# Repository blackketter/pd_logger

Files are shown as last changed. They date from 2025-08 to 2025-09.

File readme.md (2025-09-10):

# USB-C Power Delivery Measurement Tools

This repository contains two DIY gadgets to monitor and log **USB-C Power Delivery (PD)**.  
Both devices are designed to be easy to build, hackable, and useful for makers who want to explore USB-C PD.

---

## ✨ Features

- **DIY Power Meter**  
  Small device with an OLED display showing **voltage, current, and power** in real time.  
  Powered by an STM32 microcontroller.

- **PD Logger**  
  Wi-Fi enabled device based on ESP-01s.  
  Logs **voltage, current, and power** for several hours and serves interactive plots in any web browser.

---

## 📷 Devices

### Power Meter
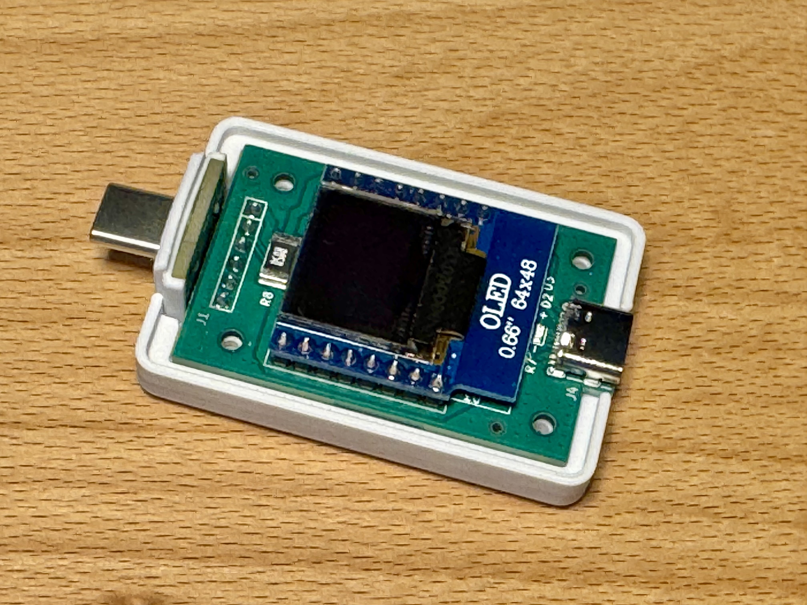
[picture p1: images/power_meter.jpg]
DIY Power Meter


### PD Logger
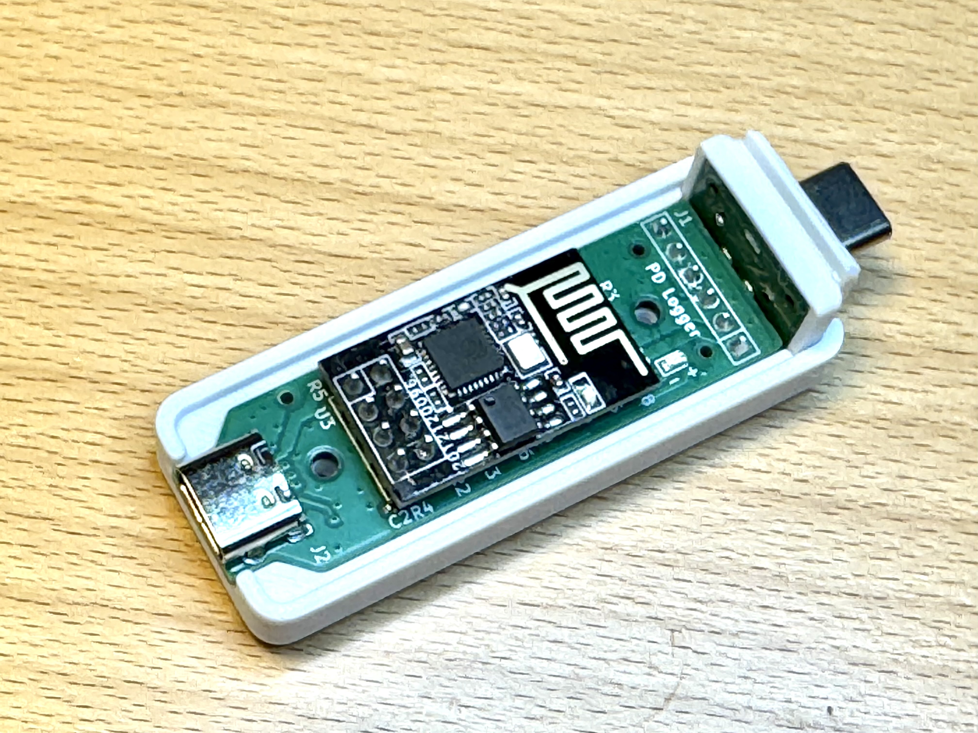
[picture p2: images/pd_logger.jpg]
PD Logger


---

## 🛠️ How it works

- **USB-C connectors**: male on the input side, female on the output side.  
- **CC & VCONN lines** are passed through to handle PD voltage negotiation.  
- **Shunt resistor (50 mΩ)** allows precise current measurement.  
- **INA219 sensor** measures voltage and current via I²C.  
- **Step-down converter** generates 3.3 V from 5–20 V input.  
- **MCUs**: STM32 with OLED display (Power Meter), ESP-01s with Wi-Fi (PD Logger).  

---

## 📦 Hardware

- **Schematics & PCB files** → in this repo (`/electronics`)  
- **PCBs manufactured by** [JLCPCB](https://jlcpcb.com)  
- **3D printable cases** → in `/mechanics`  
- **Firmware** → in `/software`

All production data is included in `/electronics` so you can **order, print, and build your own devices**.

---

## 🌐 Usage

- **Power Meter**: plug between charger and device → read values on the display.  
- **PD Logger**: connect to your local Wi-Fi, then open `http://pd-logger.local` → see live values.  
  - Update interval: 5 seconds  
  - Logging capacity: several hours  
  - Data download as CSV file  
  - Interactive plots for Voltage / Current / Power over time  

---

## 📄 License

This project is licensed under the  
**Creative Commons Attribution-NonCommercial-ShareAlike 4.0 International (CC BY-NC-SA 4.0)** license.  

You are free to **share and adapt** the material, **for non-commercial purposes only**,  
as long as you provide proper attribution and distribute your contributions under the same license.  

For details, see the [LICENSE](LICENSE) file.  

---

## 🙌 Acknowledgments

- [Hackaday CH224K USB PD Decoy project](https://hackaday.io/) for inspiration

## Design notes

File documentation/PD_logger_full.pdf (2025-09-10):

# USB-C Power Delivery Measurement Tool

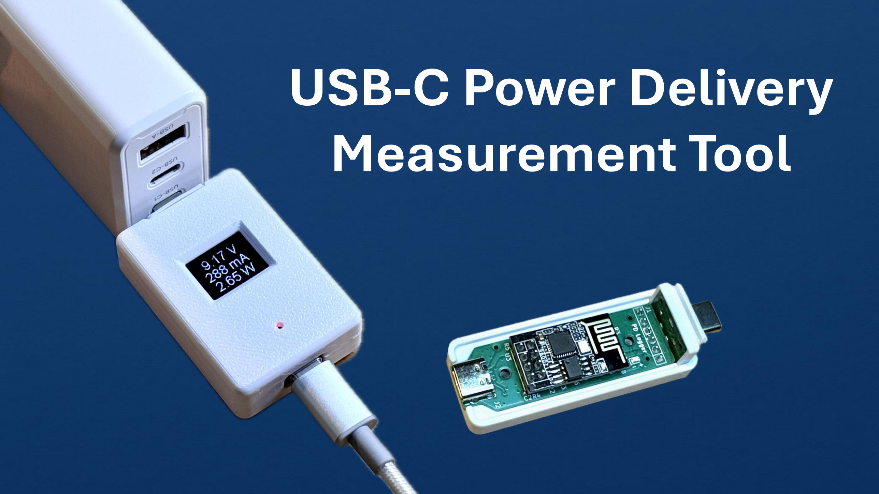
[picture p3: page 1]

## What is USB-C Power Delivery (PD)?

Universal Standard
Works across many devices (phones, laptops, tablets, accessories).

Flexible Voltage and Current
Supports multiple power profiles (5V, 9V, 12V, 15V, 20V).

Higher Power Delivery
Provides up to 100W (20V @ 5A), enabling laptop charging.

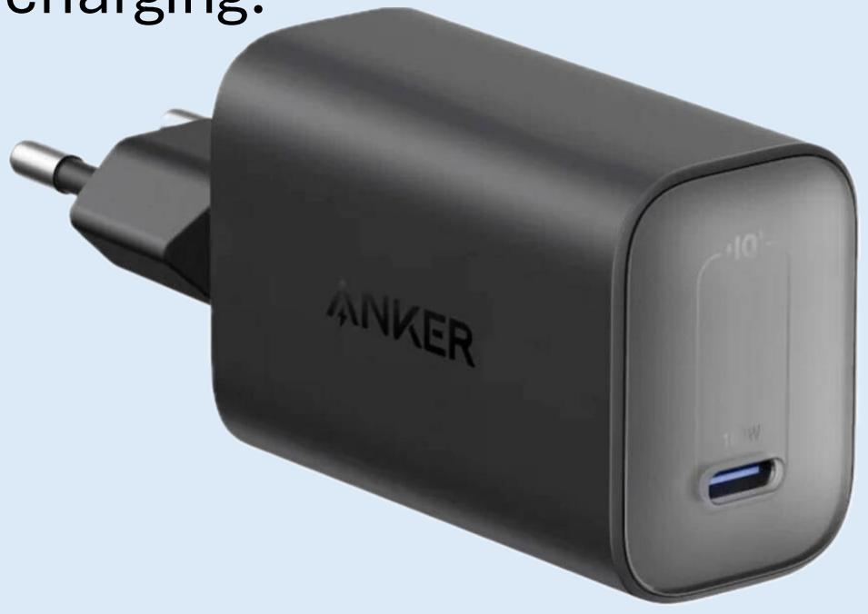
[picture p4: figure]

Smart Negotiation
Device and charger communicate to select
the safest and most efficient power level.

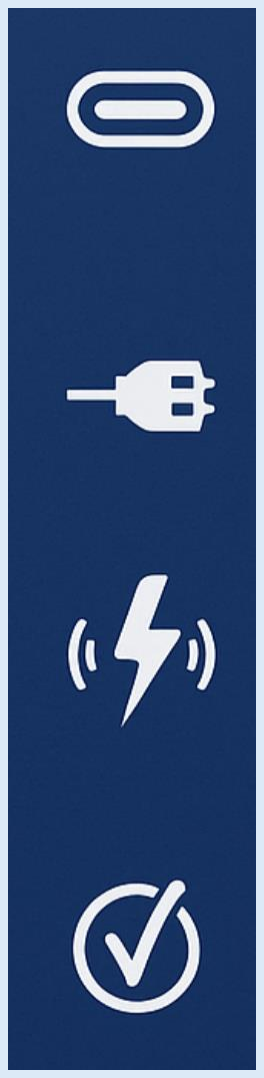
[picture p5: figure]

➔ the ideal power source for Maker projects

## USB-C PD: the Ideal Power Source for Maker Projects

## hackaday.io

- USB-C PD offers flexible voltages (5V–20V), but a controller chip is required to request the desired level.

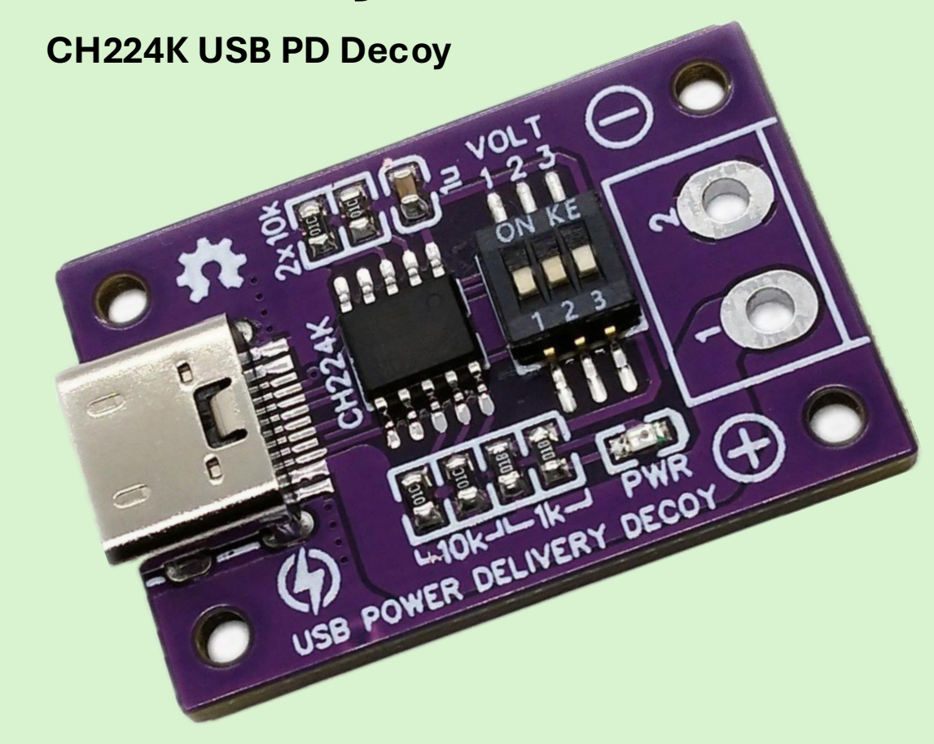
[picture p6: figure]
CH224K USB PD Decoy

- CH224K simplifies voltage negotiation, making it easy to obtain fixed outputs (e.g., 5V, 9V, 12V, 15V, 20V).
- Hackaday project + breakout board provide ready-to-use examples for quick prototyping.

## How to Measure Voltage, Current, and Power?

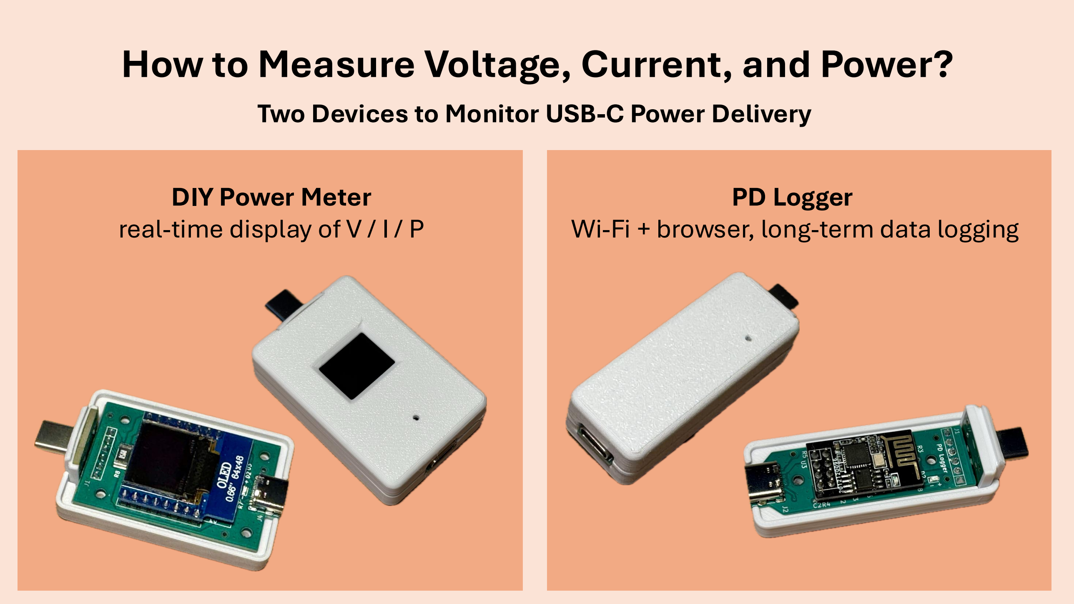
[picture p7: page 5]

Two Devices to Monitor USB-C Power Delivery

DIY Power Meter
real-time display of V / I / P

PD Logger
Wi-Fi + browser, long-term data logging

## Schematic of the Measuring Devices

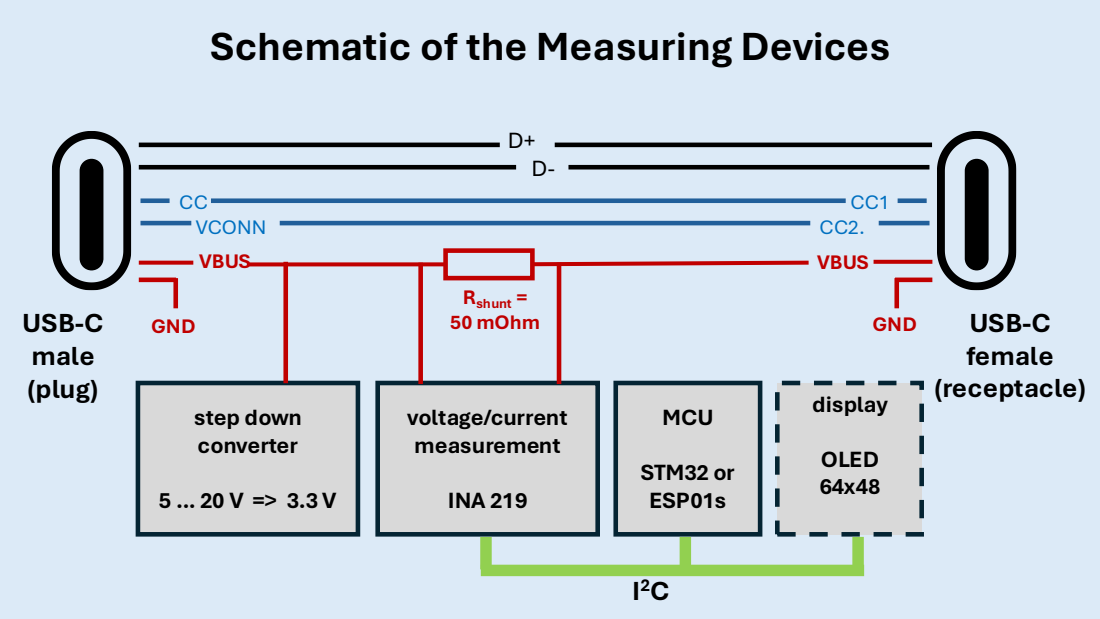
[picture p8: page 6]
USB-C male (plug); USB-C female (receptacle); CC VCONN; VBUS; GND; step down converter; voltage/current measurement; INA 219; MCU; STM32 or ESP01s; Rshunt = 50 mOhm; display; OLED 64x48

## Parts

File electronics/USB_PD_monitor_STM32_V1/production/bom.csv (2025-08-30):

Designator | Footprint | Quantity | Value | LCSC Part #
C1, C2, C3, C4, C8 | 0402 | 5 | 100n | C1525
C10, C9 | 0402 | 2 | 10p | C32949
C11 | 0805 | 1 | 10µ | C440198
C12 | 0603 | 1 | 100n | C14663
C13, C14 | 0805 | 2 | 22µ | C45783
C5 | 0603 | 1 | 10µ | C19702
C6 | 0402 | 1 | 10n | C15195
C7 | 0603 | 1 | 1µ | C15849
D1, D3 | D_SOD-123 | 2 | B5819W | C8598
D2 | 0603 | 1 | red | C2286
J1 | header_90degree_01x06_back | 1 | Conn_01x06_Pin
J2 | 4pin | 1 | Debug
J4 | USB_C_Receptacle | 1 | USB_C_Receptacle_USB2.0_16P | C709357
L1 | L_APV_APH0420 | 1 | 4µ7 | C133193
R1 | 0603 | 1 | 10k | C25804
R5, R6 | 0402 | 2 | 2k2 | C25879
R7 | 0402 | 1 | 1k | C11702
R8 | 2512 | 1 | 50 mOhm | C154681
U1 | LQFP-48_7x7mm_P0.5mm | 1 | STM32F103C8T6 | C8734
U2 | TSOT-23-6 | 1 | AP63203WU | C780769
U3 | OLED_display_0_66 | 1 | 0.66inch OLED display
U4 | SOT-23-8 | 1 | INA219AxDCN | C87469
U5, U6, U7 | JLC_tooling_hole | 3 | ~
Y1 | Crystal_SMD_3225-4Pin_3.2x2.5mm | 1 | 16MHz | C112972

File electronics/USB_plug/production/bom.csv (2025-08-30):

Designator | Footprint | Quantity | Value | LCSC Part #
J1 | header_01x06 | 1 | Conn_01x06_Pin
P1 | C168690 | 1 | USB_C_Plug | C168690
U1, U2 | JLC_tooling_hole | 2 | ~

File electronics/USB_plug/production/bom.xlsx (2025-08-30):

Designator | Footprint | Quantity | Value | LCSC Part #
P1 | C168690 | 1 | USB_C_Plug | C168690

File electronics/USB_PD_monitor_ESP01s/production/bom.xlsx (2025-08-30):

Designator | Footprint | Quantity | Value | LCSC Part #
C1, C2 | 0402 | 2 | 100 nF | C1525
C3 | 0805 | 1 | 10µ | C440198
C4 | 0603 | 1 | 100n | C14663
C5, C6 | 0805 | 2 | 22µ | C45783
D2 | 0603 | 1 | red | C2286
J2 | USB_C_Receptacle | 1 | USB_C_Receptacle_USB2.0_16P | C709357
L1 | L_APV_APH0420 | 1 | 4µ7 | C133193
R1, R2, R4, R5 | 0402 | 4 | 10k | C25744
R3 | 2512 | 1 | 50 mOhm | C154681
R8 | 0402 | 1 | 1k | C11702
U2 | SOT-23-8 | 1 | INA219AxDCN | C87469
U5 | TSOT-23-6 | 1 | AP63203WU | C780769

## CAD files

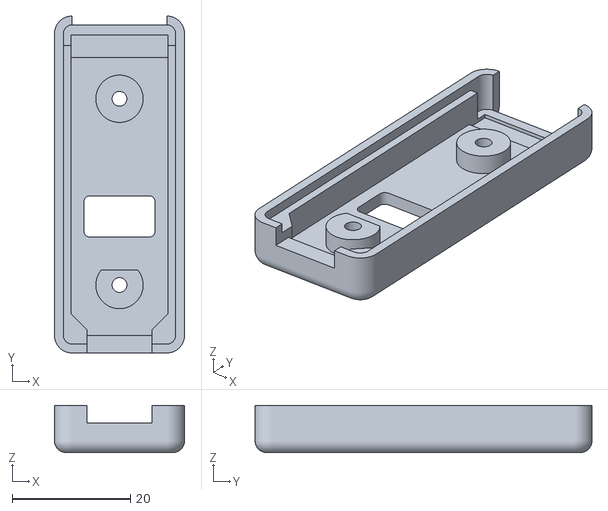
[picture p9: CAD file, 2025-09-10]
mechanics/PD_Logger/lower_case.stl
22.0 x 57.0 x 8.00

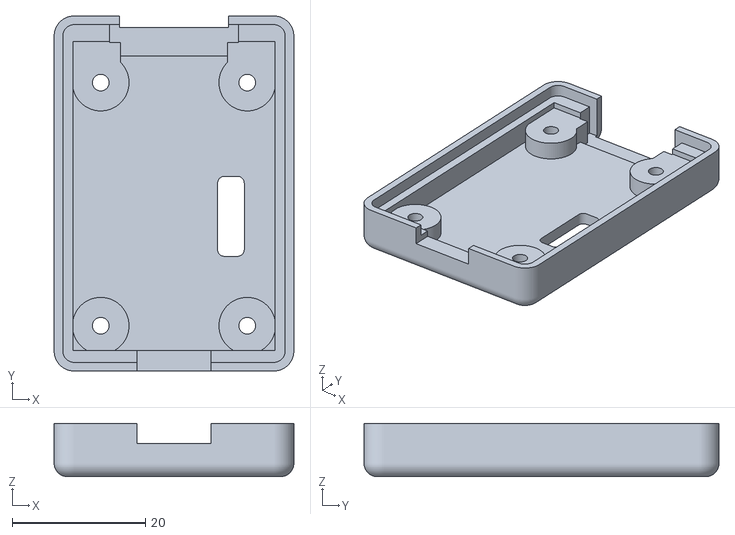
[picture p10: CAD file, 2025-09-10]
mechanics/Power_Meter/bottom_case1.stl
36.0 x 53.3 x 8.00

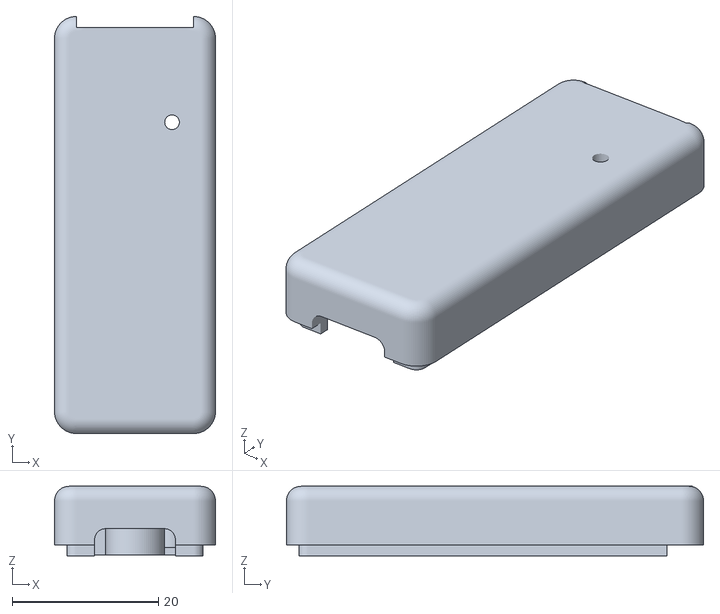
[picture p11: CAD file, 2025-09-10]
mechanics/PD_Logger/upper_case.stl
22.0 x 57.0 x 9.50

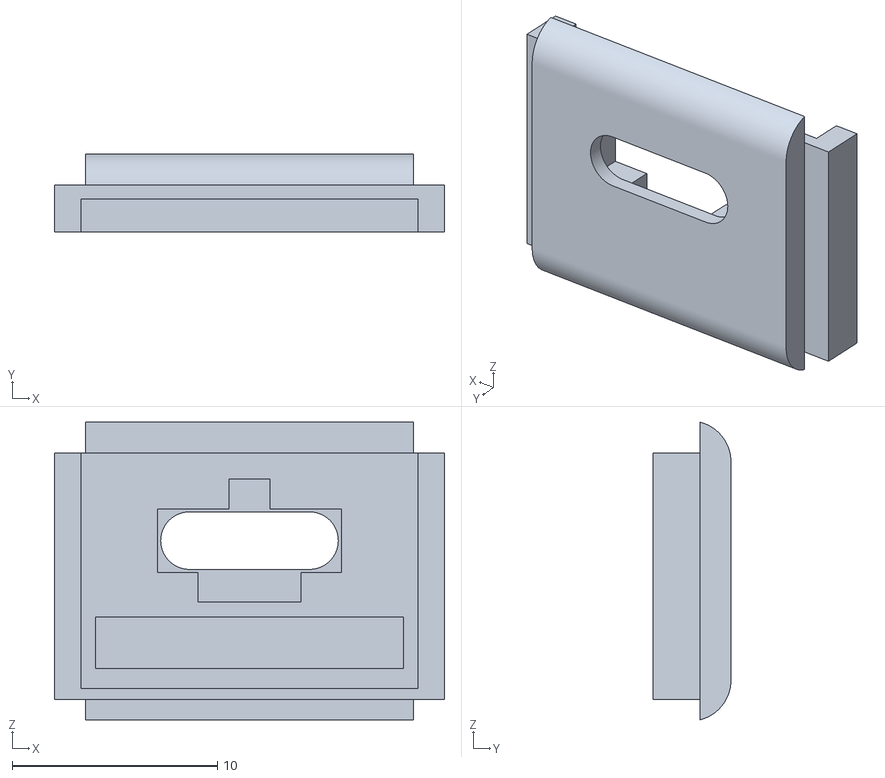
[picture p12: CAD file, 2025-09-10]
mechanics/Power_Meter/insert1.stl
19.0 x 3.80 x 14.5

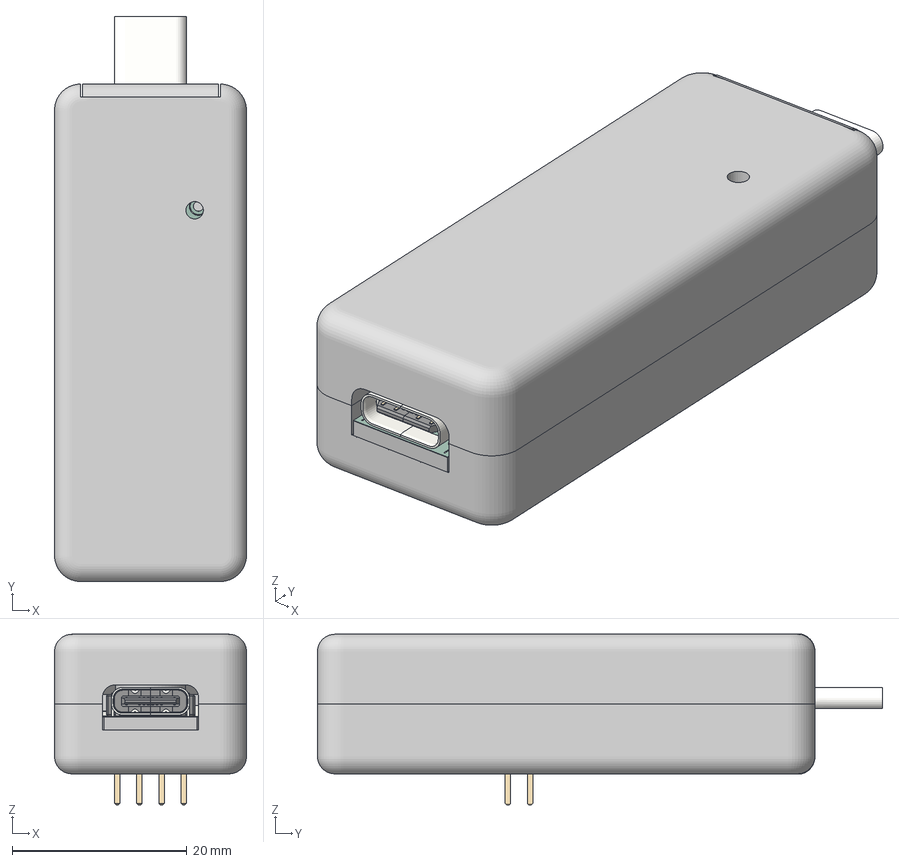
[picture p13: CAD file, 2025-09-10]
mechanics/PD_Logger/PD_logger_case v15.3mf
22.0 x 64.7 x 19.5 mm
Körper1 x 35
Körper10 x 10
Körper100 x 2
Körper101 x 2
Körper102 x 2
Körper103 x 2
Körper104 x 2
Körper105 x 2
Körper106 x 2
Körper107 x 2
Körper108 x 2
Körper109 x 2
Körper11 x 10
Körper110 x 2
Körper111 x 2
Körper112 x 2
Körper113 x 2
Körper114 x 2
Körper115 x 2
Körper116 x 2
Körper117
Körper118
Körper119
Körper12 x 10
Körper120
Körper121
Körper122
Körper123
Körper124
Körper125
Körper126
Körper127
Körper128
Körper129
Körper13 x 9
Körper130
Körper131
Körper132
Körper133
Körper134
Körper135
Körper136
Körper137
Körper138
Körper14 x 9
Körper15 x 9
Körper16 x 9
Körper17 x 9
Körper18 x 9
Körper19 x 8
Körper2 x 16
Körper20 x 8
Körper21 x 8
Körper22 x 8
Körper23 x 8
Körper24 x 8
Körper25 x 8
Körper26 x 8
Körper27 x 8
Körper28 x 8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

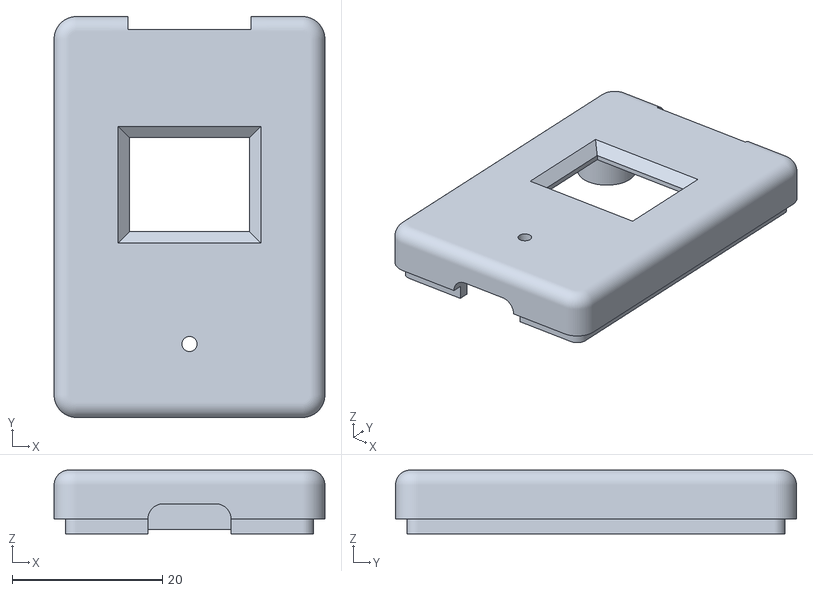
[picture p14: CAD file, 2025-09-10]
mechanics/Power_Meter/top_case1.stl
36.0 x 53.3 x 8.50

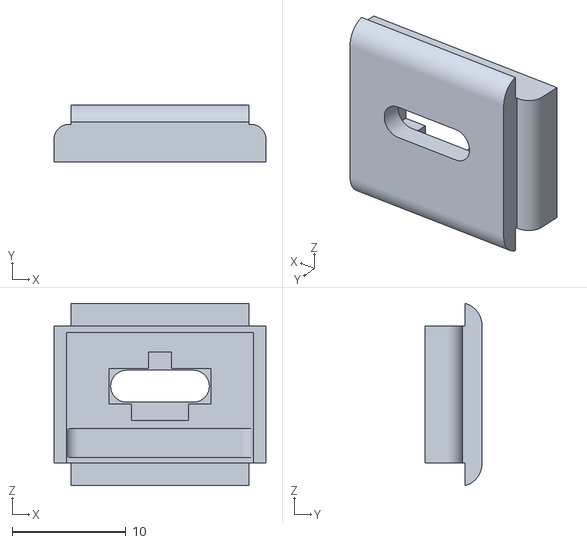
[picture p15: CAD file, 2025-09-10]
mechanics/PD_Logger/insert.stl
18.6 x 5.00 x 16.0

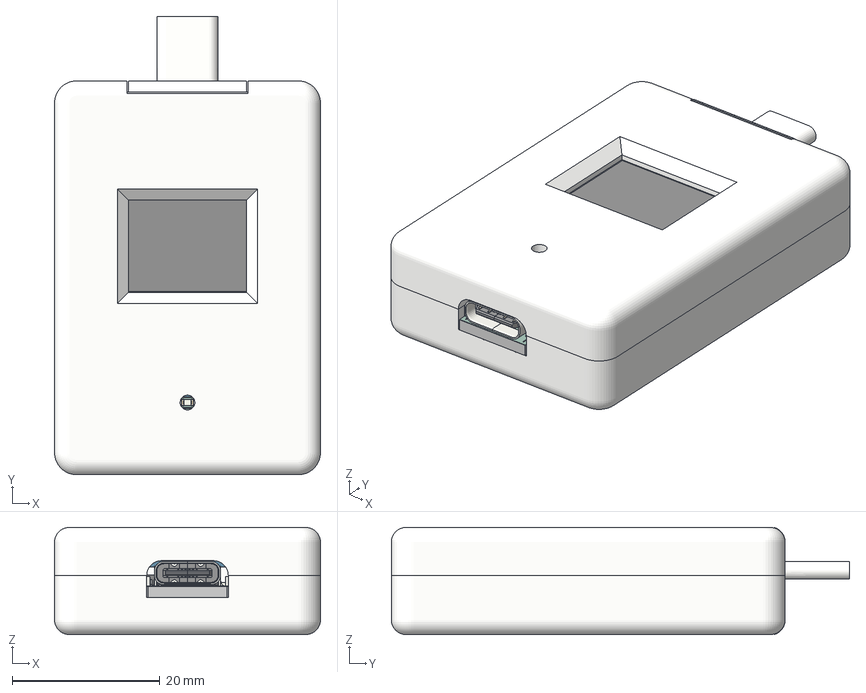
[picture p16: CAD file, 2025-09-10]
mechanics/Power_Meter/USB_PD_monitor v23.3mf
36.0 x 62.0 x 14.5 mm
Körper1 x 43
Körper10 x 9
Körper100 x 3
Körper101 x 3
Körper102 x 3
Körper103 x 3
Körper104 x 3
Körper105 x 3
Körper106 x 3
Körper107 x 3
Körper108 x 3
Körper109 x 3
Körper11 x 9
Körper110 x 3
Körper111 x 3
Körper112 x 3
Körper113 x 3
Körper114 x 3
Körper115 x 3
Körper116 x 3
Körper117 x 3
Körper118 x 3
Körper119 x 3
Körper12 x 9
Körper120 x 3
Körper121 x 3
Körper122 x 3
Körper123 x 3
Körper124 x 3
Körper125 x 3
Körper126 x 3
Körper127 x 3
Körper128 x 3
Körper129 x 3
Körper13 x 8
Körper130 x 3
Körper131 x 3
Körper132 x 3
Körper133 x 3
Körper134 x 3
Körper135 x 3
Körper136 x 3
Körper137 x 3
Körper138 x 3
Körper139 x 3
Körper14 x 8
Körper140 x 3
Körper141 x 3
Körper142 x 3
Körper143 x 3
Körper144 x 3
Körper145 x 3
Körper146 x 3
Körper147 x 3
Körper148 x 3
Körper149 x 2
Körper15 x 8
Körper150 x 2
Körper151 x 2
Körper152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

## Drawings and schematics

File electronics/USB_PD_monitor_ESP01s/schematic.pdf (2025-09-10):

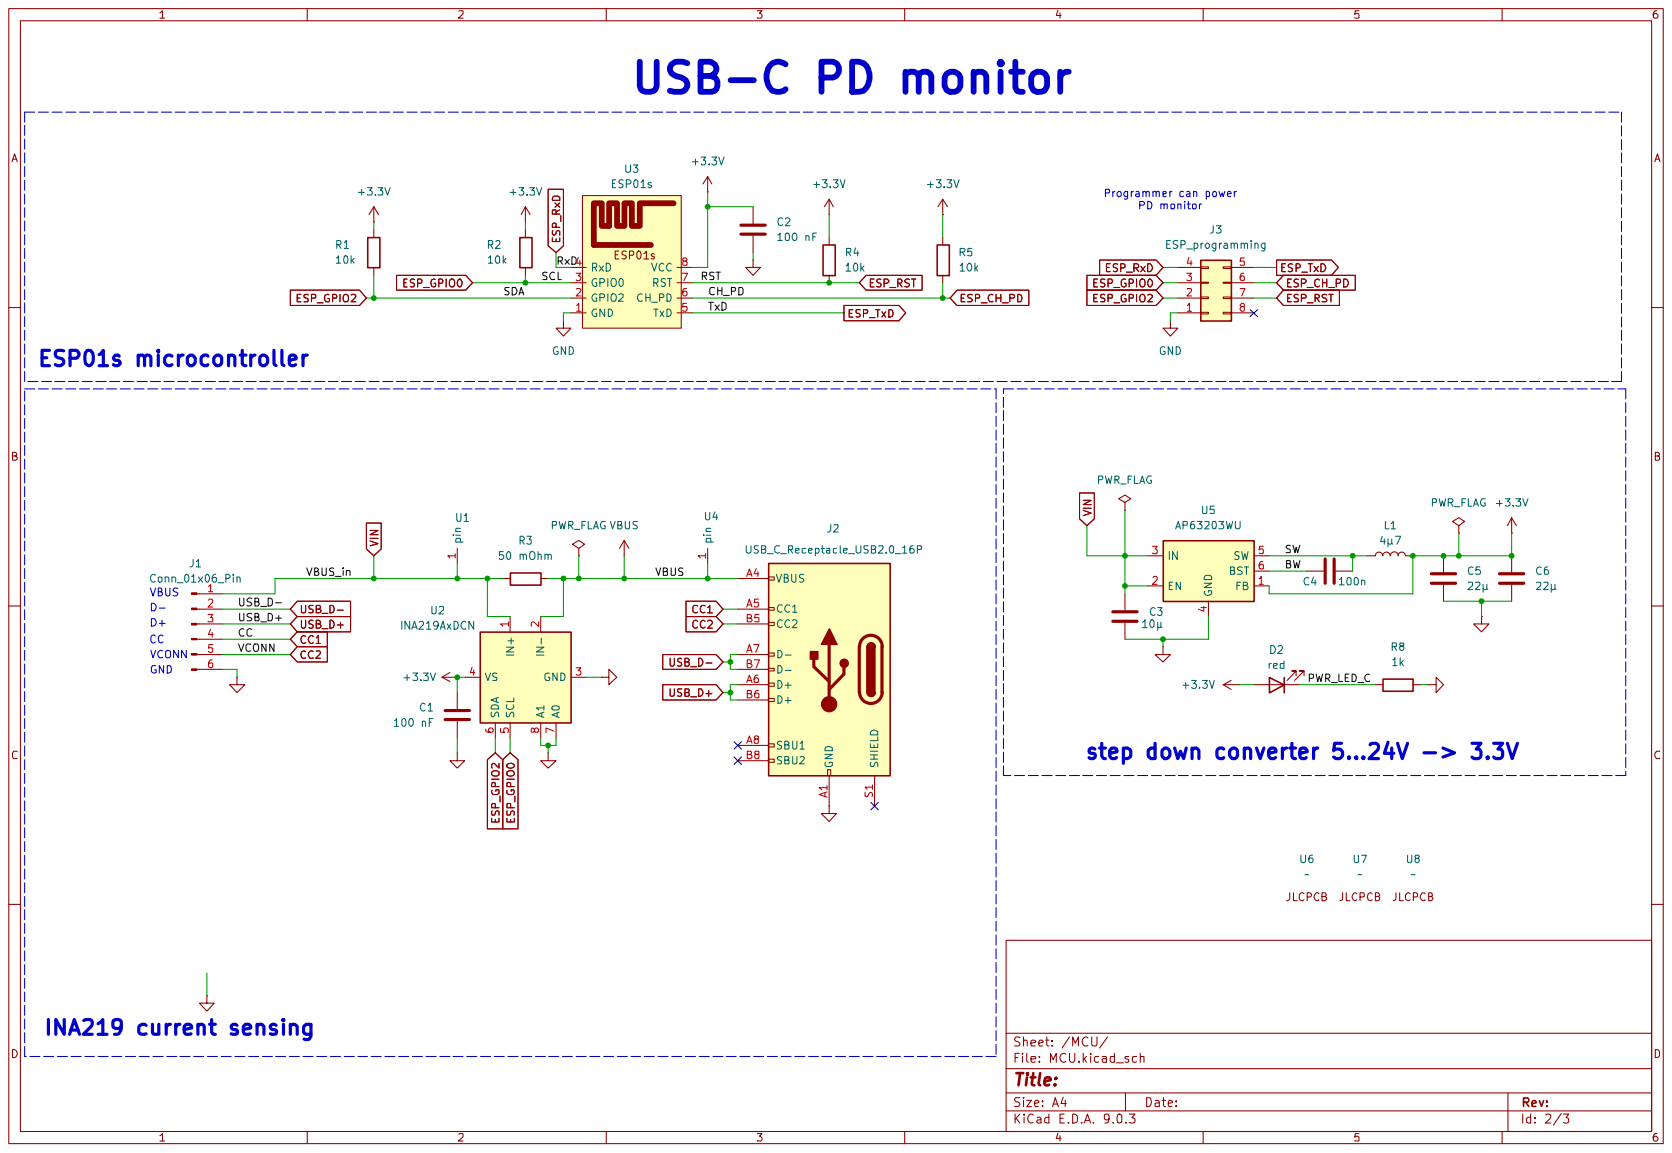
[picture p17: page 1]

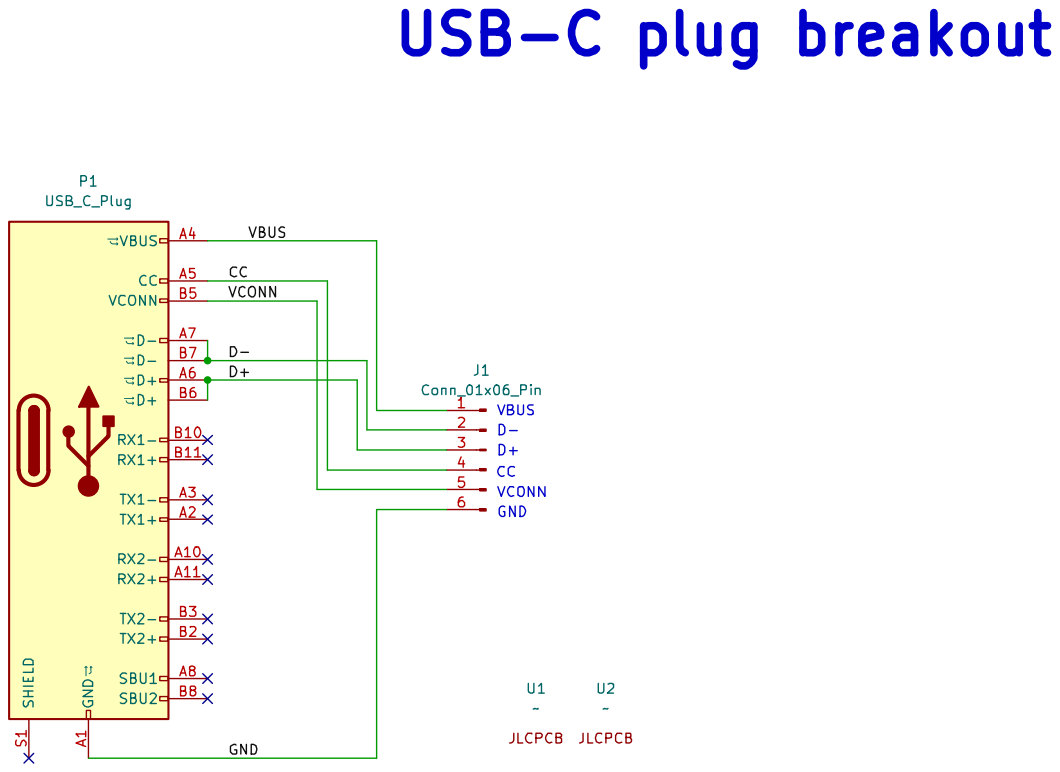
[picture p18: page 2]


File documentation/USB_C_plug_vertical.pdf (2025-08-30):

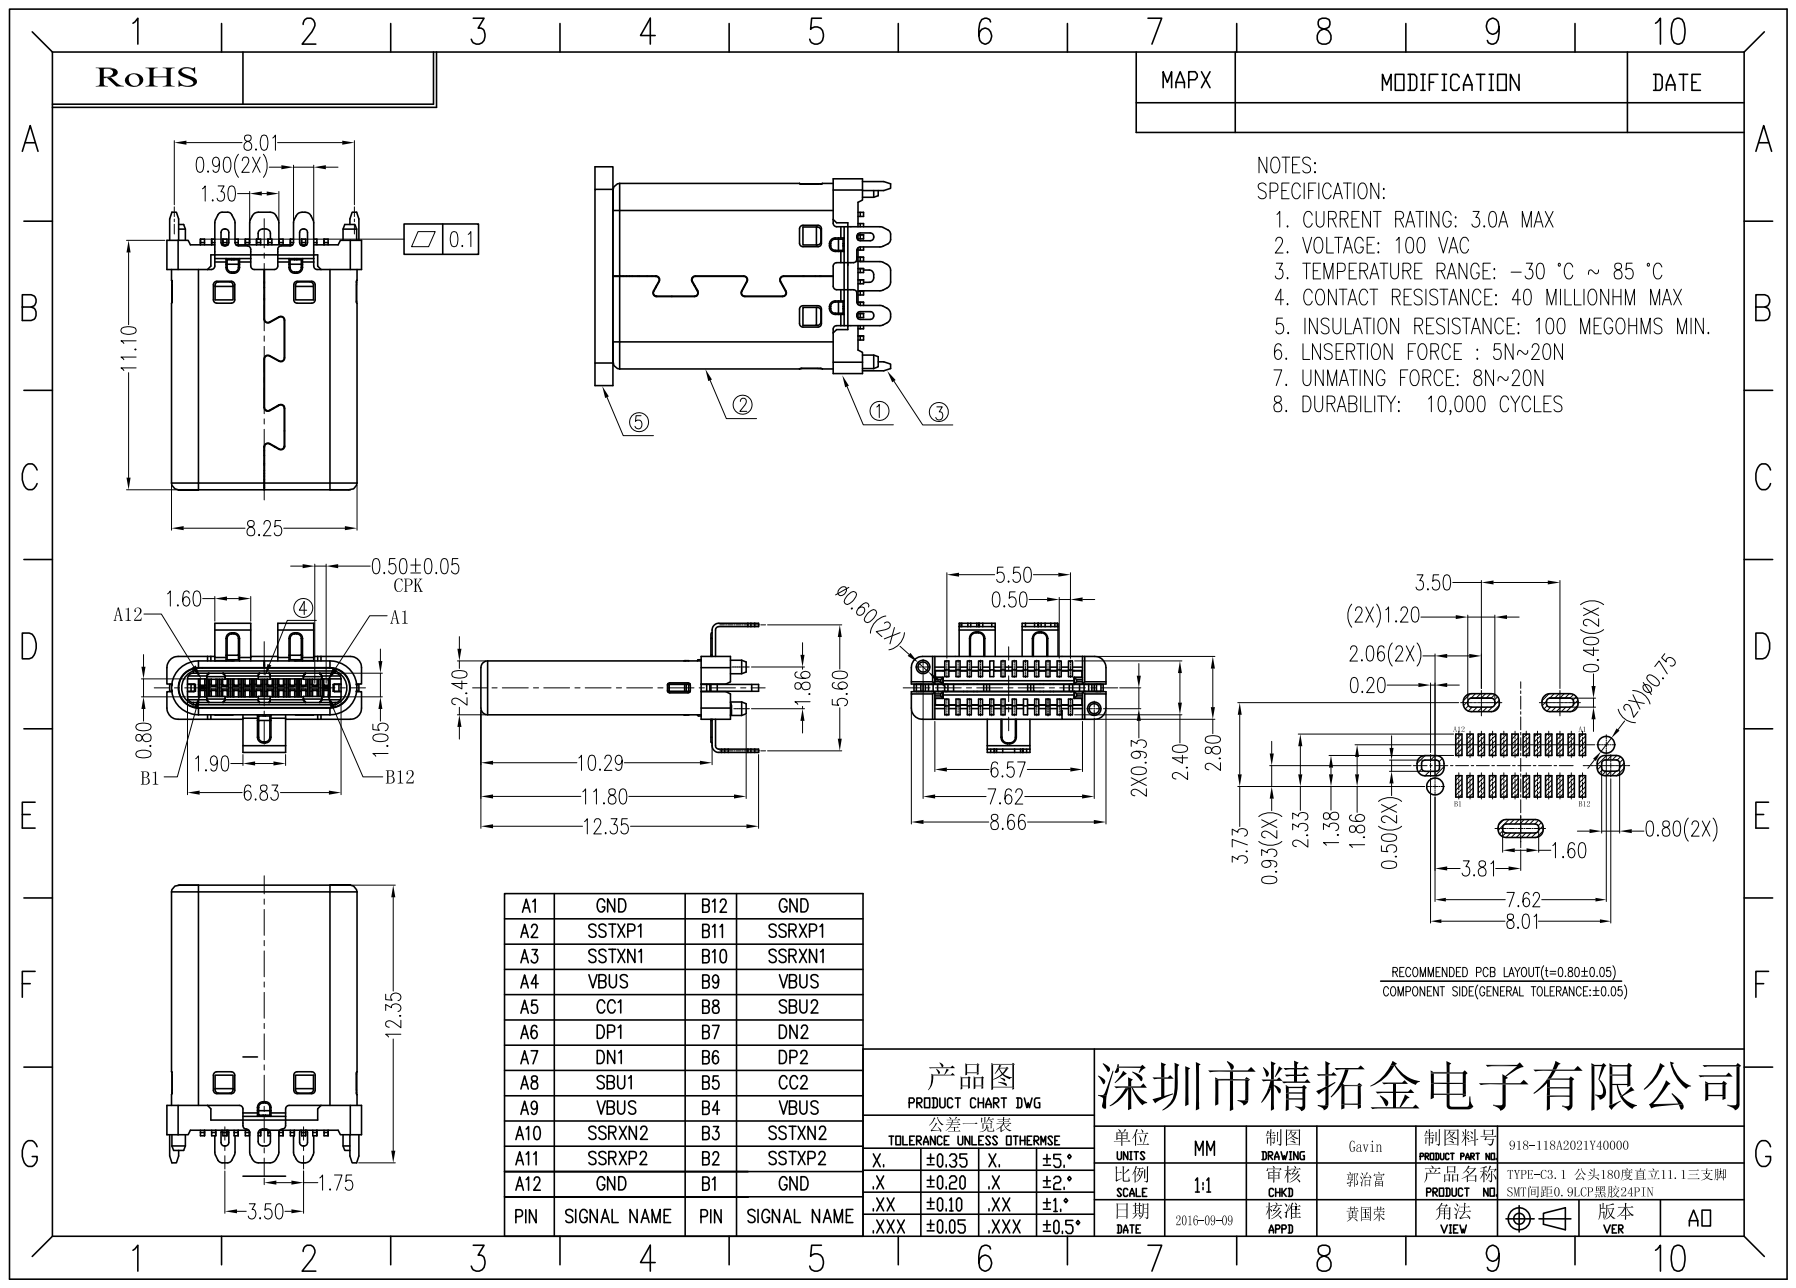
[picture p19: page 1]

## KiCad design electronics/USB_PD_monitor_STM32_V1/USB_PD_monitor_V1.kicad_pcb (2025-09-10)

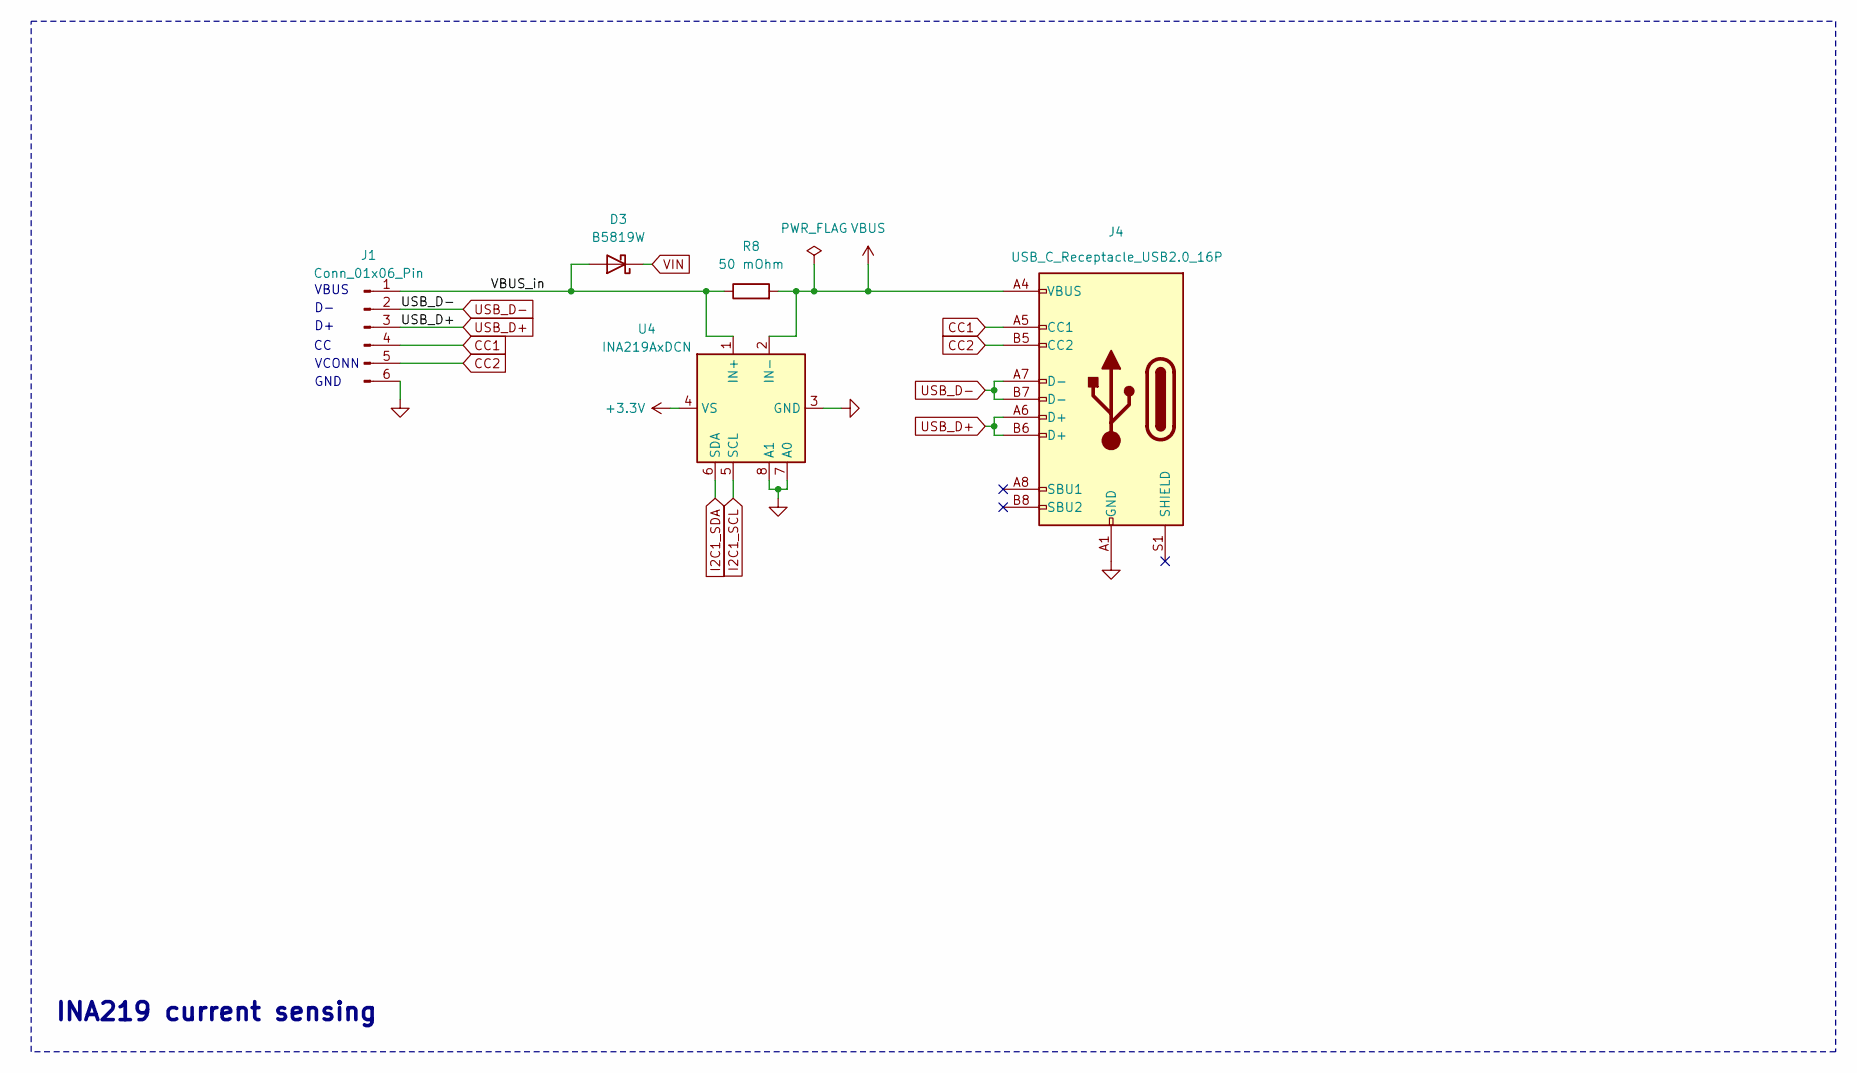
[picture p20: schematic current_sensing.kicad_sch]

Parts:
D3: B5819W; D_SOD-123; LCSC C8598
J1: Conn_01x06_Pin; header_90degree_01x06_back
J4: USB_C_Receptacle_USB2.0_16P; USB_C_Receptacle; LCSC C709357
R8: 50 mOhm; R_2512_6332Metric; LCSC C154681
U4: INA219AxDCN; SOT-23-8; LCSC C87469

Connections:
+3.3V: U4.4 (VS); also elsewhere on the board
/current_sensing/VBUS_in: D3.2 (A), J1.1, R8.1, U4.1 (IN+)
CC1: J1.4, J4.A5 (CC1)
CC2: J1.5, J4.B5 (CC2)
GND: J1.6, J4.A1 (GND), J4.A12 (GND), J4.B1 (GND), J4.B12 (GND), U4.3 (GND), U4.7 (A0), U4.8 (A1); also elsewhere on the board
I2C1_SCL: U4.5 (SCL); also elsewhere on the board
I2C1_SDA: U4.6 (SDA); also elsewhere on the board
USB_D+: J1.3, J4.A6 (D+), J4.B6 (D+)
USB_D-: J1.2, J4.A7 (D-), J4.B7 (D-)
VBUS: J4.A4 (VBUS), J4.A9 (VBUS), J4.B4 (VBUS), J4.B9 (VBUS), R8.2, U4.2 (IN-)
VIN: D3.1 (K); also elsewhere on the board

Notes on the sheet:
VBUS
VCONN
GND
INA219 current sensing

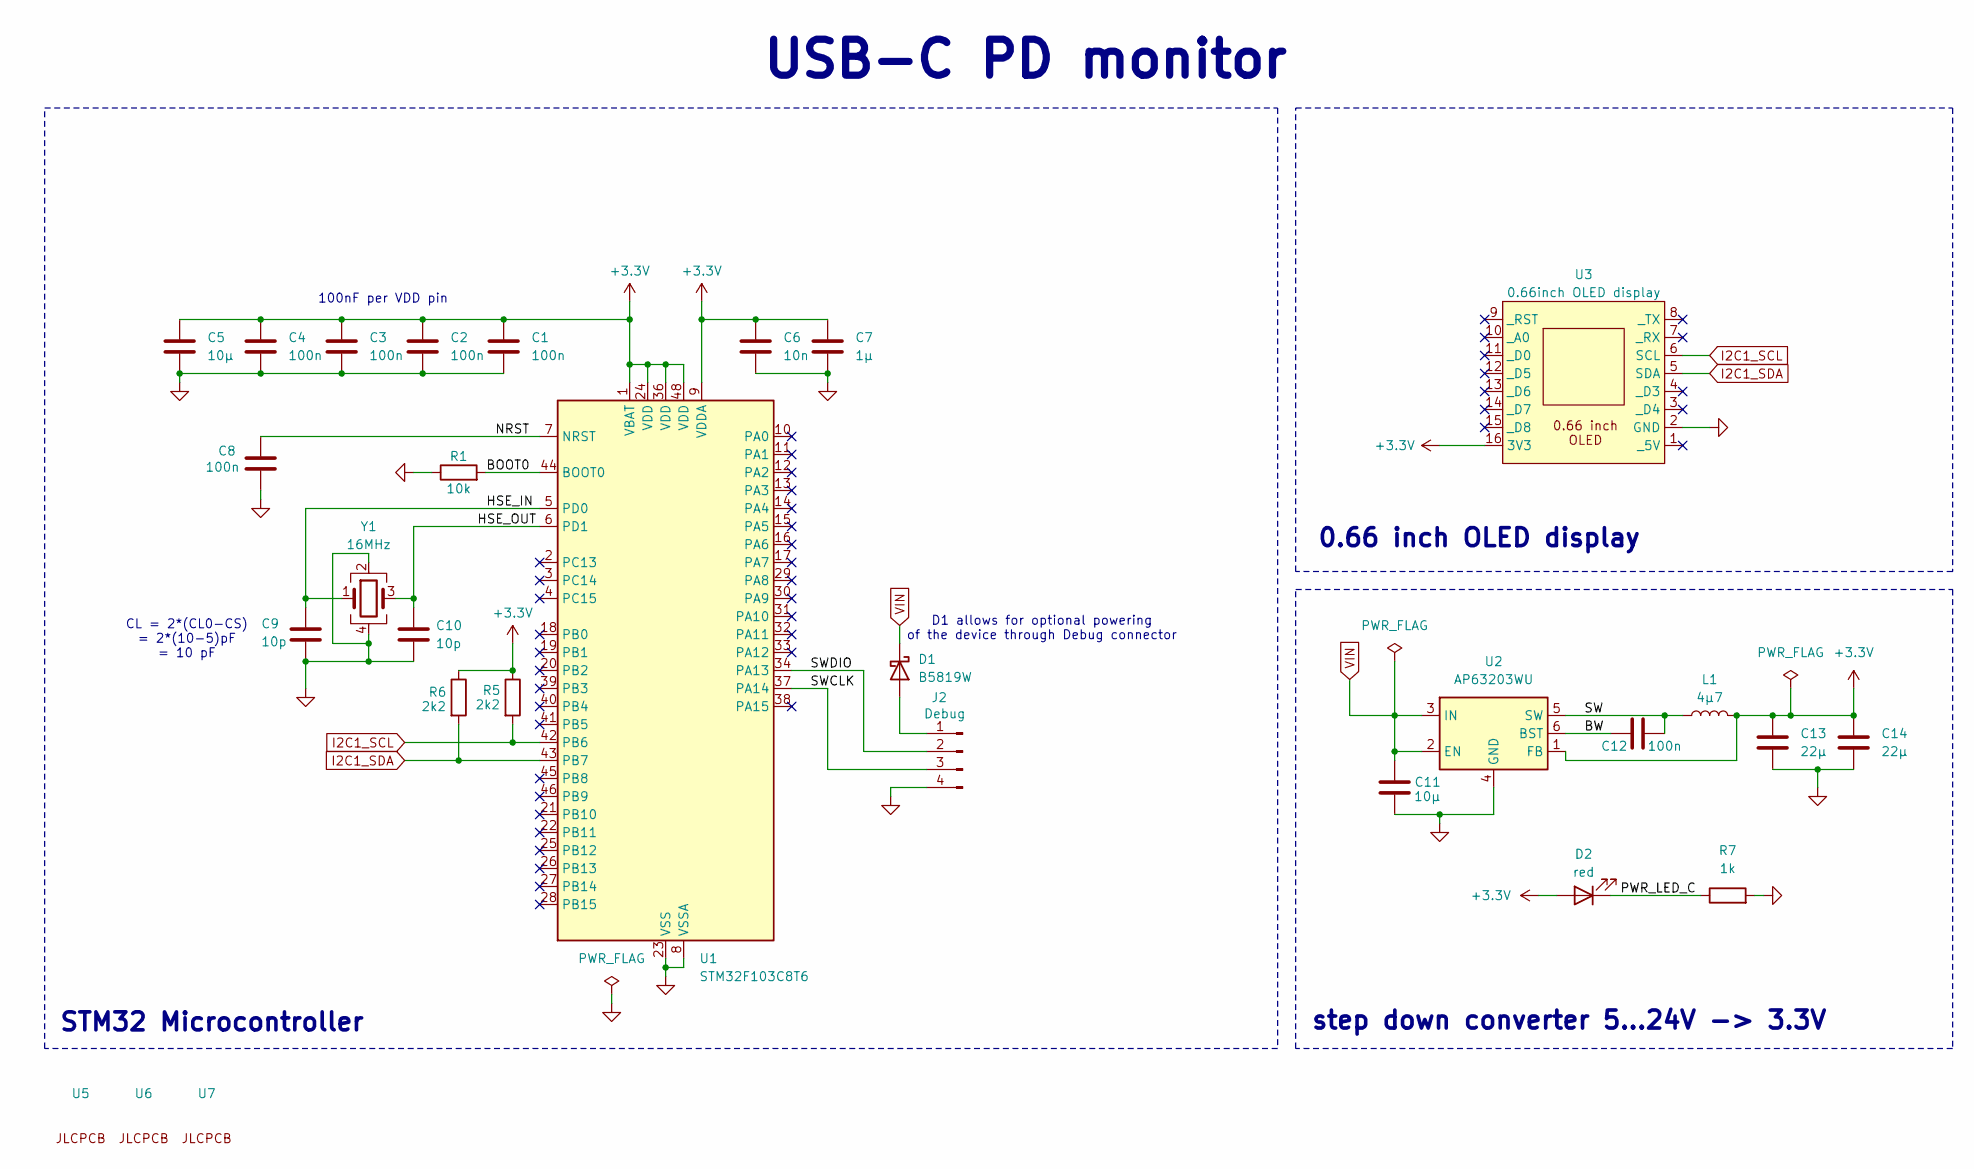
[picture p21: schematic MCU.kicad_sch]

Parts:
C1, C2, C3, C4, C8: 100n; C_0402_1005Metric; LCSC C1525
C5: 10µ; C_0603_1608Metric; LCSC C19702
C6: 10n; C_0402_1005Metric; LCSC C15195
C7: 1µ; C_0603_1608Metric; LCSC C15849
C9, C10: 10p; C_0402_1005Metric; LCSC C32949
C11: 10µ; C_0805_2012Metric; LCSC C440198
C12: 100n; C_0603_1608Metric; LCSC C14663
C13, C14: 22µ; C_0805_2012Metric; LCSC C45783
D1: B5819W; D_SOD-123; LCSC C8598
D2: red; LED_0603_1608Metric; LCSC C2286
J2: Debug; 4pin
L1: 4µ7; L_APV_APH0420; LCSC C133193
R1: 10k; R_0603_1608Metric; LCSC C25804
R5, R6: 2k2; R_0402_1005Metric; LCSC C25879
R7: 1k; R_0402_1005Metric; LCSC C11702
U1: STM32F103C8T6; LQFP-48_7x7mm_P0.5mm; LCSC C8734
U2: AP63203WU; TSOT-23-6; LCSC C780769
U3: 0.66inch OLED display; OLED_display_0_66
U5, U6, U7: JLC_tooling_hole
Y1: 16MHz; Crystal_SMD_3225-4Pin_3.2x2.5mm; LCSC C112972

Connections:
+3.3V: C1.1, C2.1, C3.1, C4.1, C5.1, C6.1, C7.1, C13.1, C14.1, D2.2 (A), L1.2, R5.1, R6.1, U1.1 (VBAT), U1.9 (VDDA), U1.24 (VDD), U1.36 (VDD), U1.48 (VDD), U2.1 (FB), U3.16 (3V3); also elsewhere on the board
/MCU/BOOT0: R1.2, U1.44 (BOOT0)
/MCU/BW: C12.1, U2.6 (BST)
/MCU/HSE_IN: C9.1, U1.5 (PD0), Y1.1
/MCU/HSE_OUT: C10.1, U1.6 (PD1), Y1.3
/MCU/NRST: C8.1, U1.7 (NRST)
/MCU/PWR_LED_C: D2.1 (K), R7.1
/MCU/SW: C12.2, L1.1, U2.5 (SW)
/MCU/SWCLK: J2.3, U1.37 (PA14)
/MCU/SWDIO: J2.2, U1.34 (PA13)
GND: C1.2, C2.2, C3.2, C4.2, C5.2, C6.2, C7.2, C8.2, C9.2, C10.2, C11.2, C13.2, C14.2, J2.4, R1.1, R7.2, U1.8 (VSSA), U1.23 (VSS), U1.35 (VSS), U1.47 (VSS), U2.4 (GND), U3.2 (GND), Y1.2, Y1.4; also elsewhere on the board
I2C1_SCL: R5.2, U1.42 (PB6), U3.6 (SCL); also elsewhere on the board
I2C1_SDA: R6.2, U1.43 (PB7), U3.5 (SDA); also elsewhere on the board
unnamed: D1.2 (A), J2.1
VIN: C11.1, D1.1 (K), U2.2 (EN), U2.3 (IN); also elsewhere on the board

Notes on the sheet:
100nF per VDD pin
step down converter 5...24V -> 3.3V
CL = 2*(CL0-CS) = 2*(10-5)pF = 10 pF
D1 allows for optional powering of the device through Debug connector
0.66 inch OLED display
STM32 Microcontroller
USB-C PD monitor

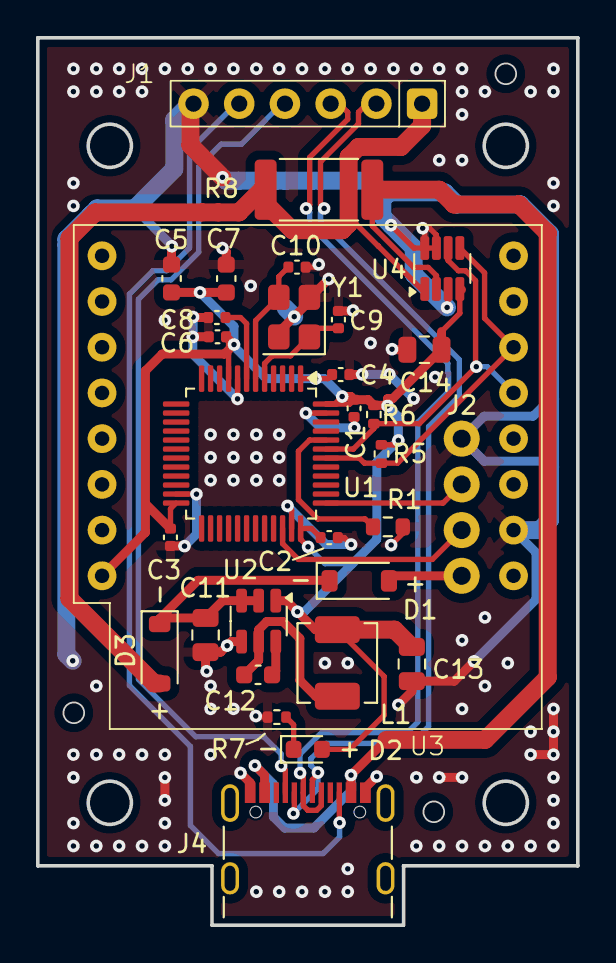
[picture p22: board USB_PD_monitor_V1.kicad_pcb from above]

Board: 2 copper layers, 30.0 x 49.3 mm, 34 parts (0 on the bottom side), 21 nets.

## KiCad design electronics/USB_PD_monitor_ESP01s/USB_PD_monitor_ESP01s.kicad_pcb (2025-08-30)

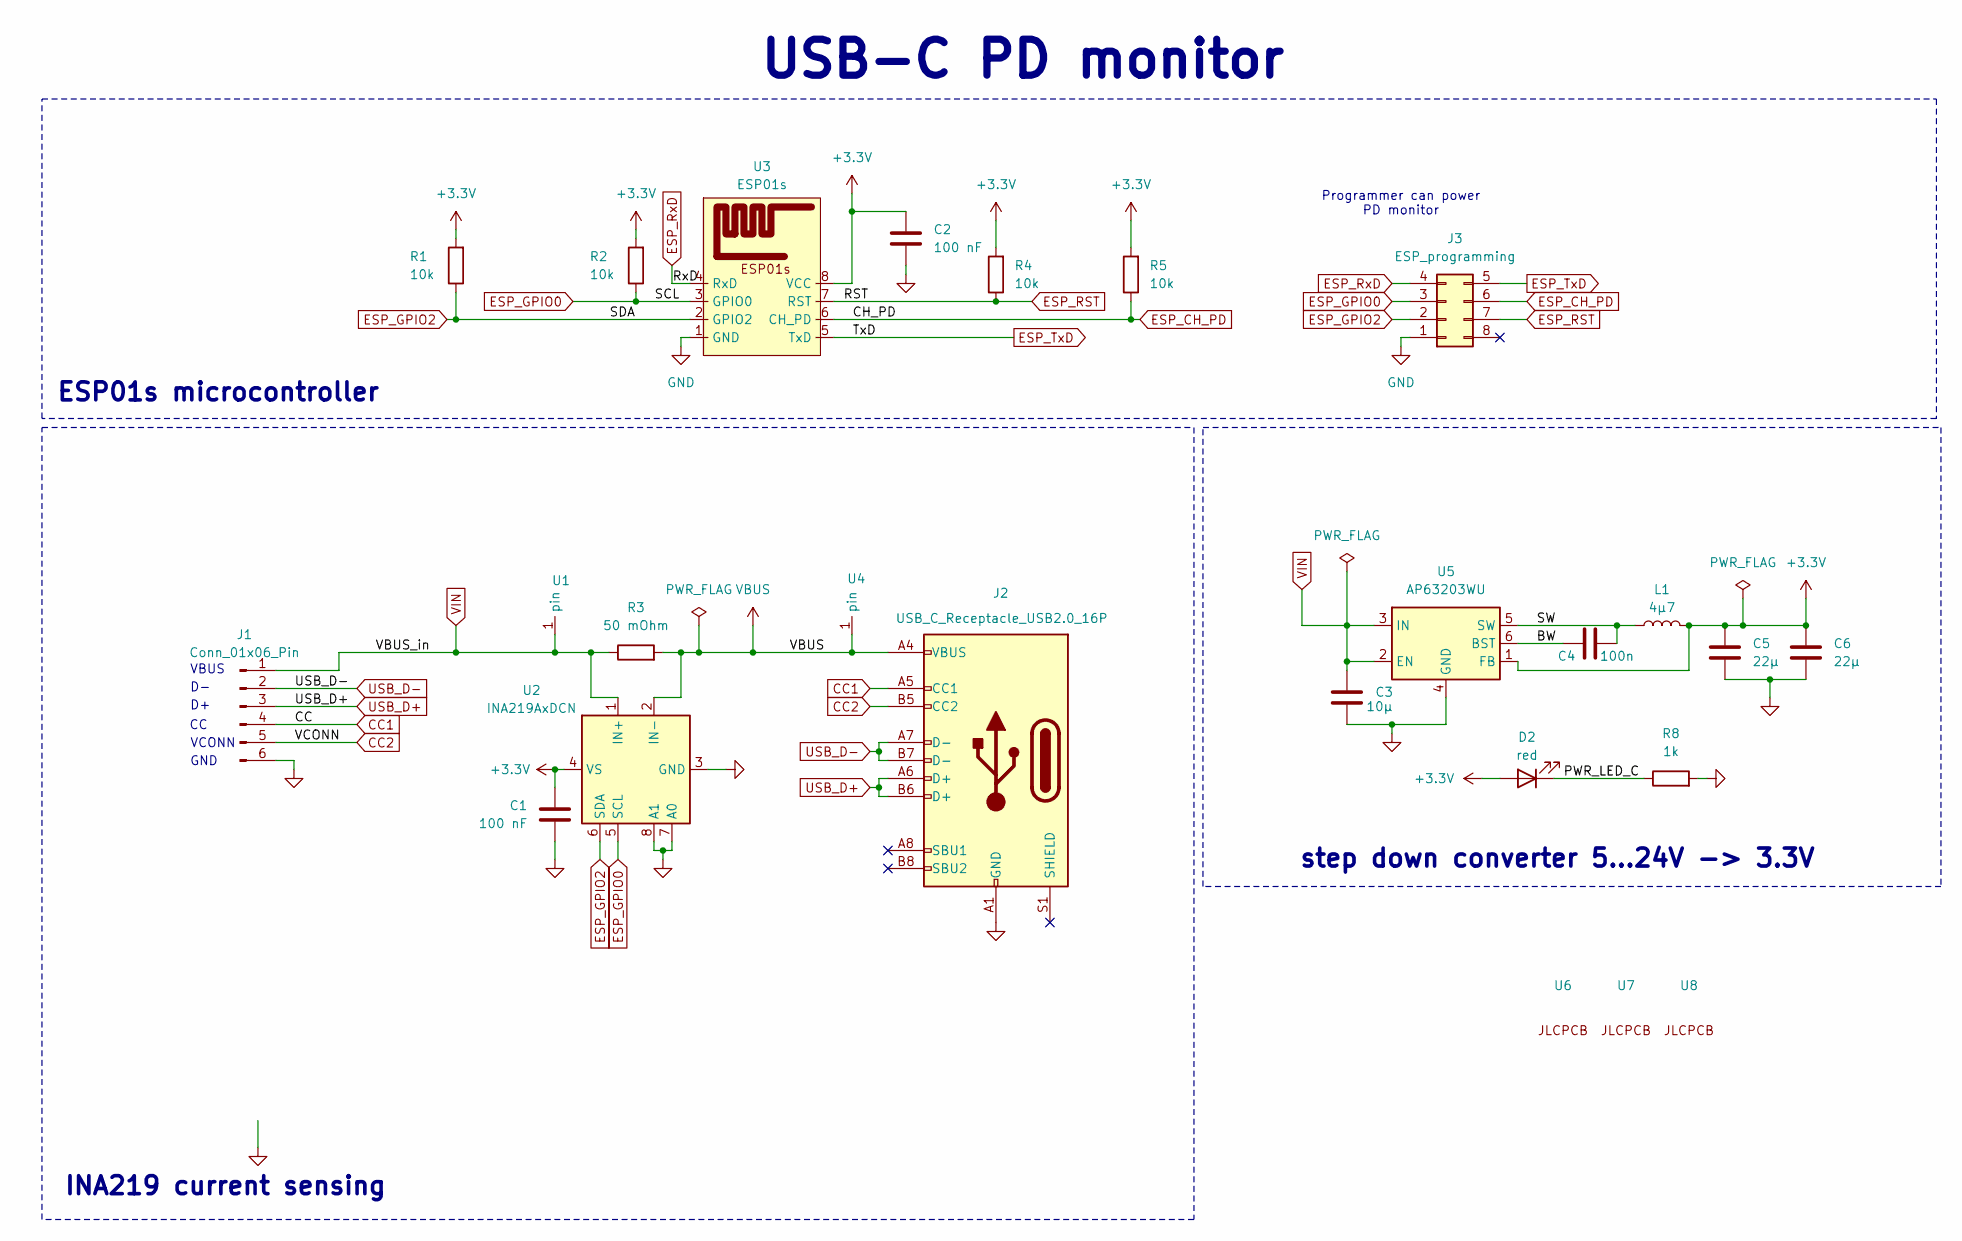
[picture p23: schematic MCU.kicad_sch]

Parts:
C1, C2: 100 nF; C_0402_1005Metric; LCSC C1525
C3: 10µ; C_0805_2012Metric; LCSC C440198
C4: 100n; C_0603_1608Metric; LCSC C14663
C5, C6: 22µ; C_0805_2012Metric; LCSC C45783
D2: red; LED_0603_1608Metric; LCSC C2286
J1: Conn_01x06_Pin; header_90degree_01x06_back
J2: USB_C_Receptacle_USB2.0_16P; USB_C_Receptacle; LCSC C709357
J3: ESP_programming; Header_ESP01
L1: 4µ7; L_APV_APH0420; LCSC C133193
R1, R2, R4, R5: 10k; R_0402_1005Metric; LCSC C25744
R3: 50 mOhm; R_2512_6332Metric; LCSC C154681
R8: 1k; R_0402_1005Metric; LCSC C11702
U1, U4: 1pin
U2: INA219AxDCN; SOT-23-8; LCSC C87469
U3: ESP01s; ESP-01
U5: AP63203WU; TSOT-23-6; LCSC C780769
U6, U7, U8: JLC_tooling_hole

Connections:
+3.3V: C1.1, C2.1, C5.1, C6.1, D2.2 (A), L1.2, R1.2, R2.2, R4.2, R5.2, U2.4 (VS), U3.8 (VCC), U5.1 (FB)
/MCU/BW: C4.1, U5.6 (BST)
/MCU/PWR_LED_C: D2.1 (K), R8.1
/MCU/SW: C4.2, L1.1, U5.5 (SW)
CC1: J1.4, J2.A5 (CC1)
CC2: J1.5, J2.B5 (CC2)
ESP_CH_PD: J3.6, R5.1, U3.6 (CH_PD)
ESP_GPIO0: J3.3, R2.1, U2.5 (SCL), U3.3 (GPIO0)
ESP_GPIO2: J3.2, R1.1, U2.6 (SDA), U3.2 (GPIO2)
ESP_RST: J3.7, R4.1, U3.7 (RST)
ESP_RxD: J3.4, U3.4 (RxD)
ESP_TxD: J3.5, U3.5 (TxD)
GND: C1.2, C2.2, C3.2, C5.2, C6.2, J1.6, J2.A1 (GND), J2.A12 (GND), J2.B1 (GND), J2.B12 (GND), J3.1, R8.2, U2.3 (GND), U2.7 (A0), U2.8 (A1), U3.1 (GND), U5.4 (GND)
USB_D+: J1.3, J2.A6 (D+), J2.B6 (D+)
USB_D-: J1.2, J2.A7 (D-), J2.B7 (D-)
VBUS: J2.A4 (VBUS), J2.A9 (VBUS), J2.B4 (VBUS), J2.B9 (VBUS), R3.2, U2.2 (IN-), U4.1 (pin)
VIN: C3.1, J1.1, R3.1, U1.1 (pin), U2.1 (IN+), U5.2 (EN), U5.3 (IN)

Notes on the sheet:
VCONN
VBUS
Programmer can power PD monitor
step down converter 5...24V -> 3.3V
GND
INA219 current sensing
ESP01s microcontroller
USB-C PD monitor

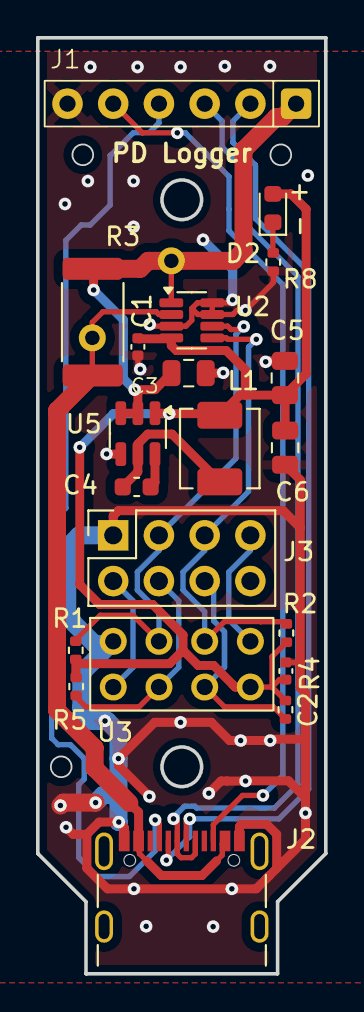
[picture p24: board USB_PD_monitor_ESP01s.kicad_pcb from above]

Board: 2 copper layers, 16.0 x 52.0 mm, 25 parts (0 on the bottom side), 17 nets.

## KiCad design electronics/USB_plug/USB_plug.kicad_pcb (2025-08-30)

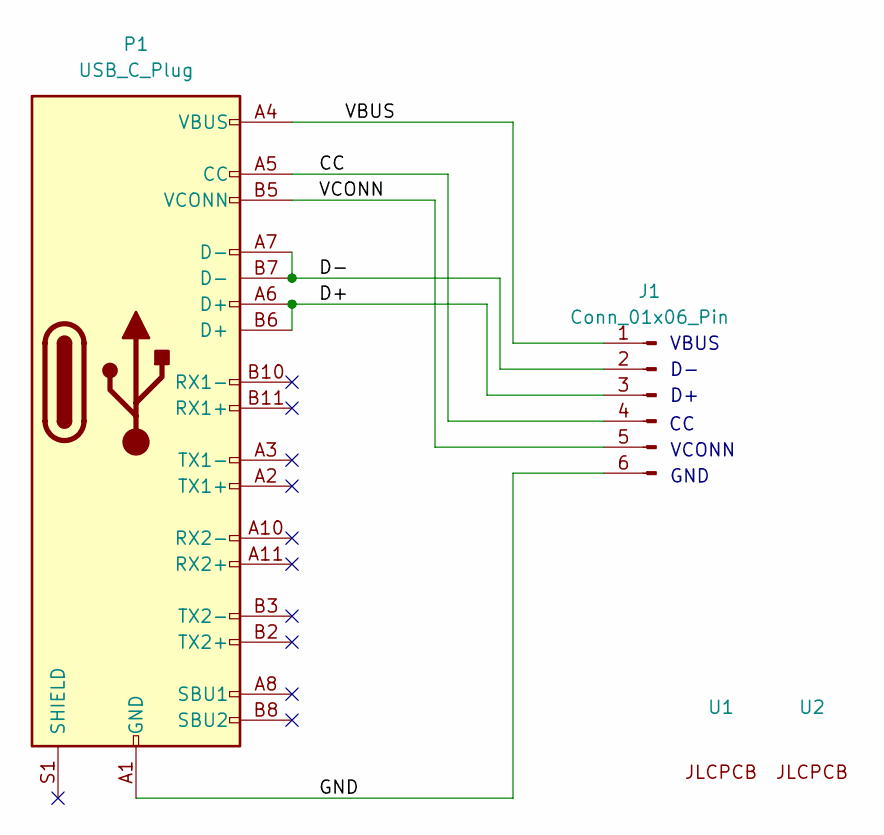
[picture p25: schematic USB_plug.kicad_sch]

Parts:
J1: Conn_01x06_Pin; header_01x06
P1: USB_C_Plug; C168690; LCSC C168690
U1, U2: JLC_tooling_hole

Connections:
/CC: J1.4, P1.A5 (CC)
/D+: J1.3, P1.A6 (D+), P1.B6 (D+)
/D-: J1.2, P1.A7 (D-), P1.B7 (D-)
/GND: J1.6, P1.A1 (GND), P1.A12 (GND), P1.B1 (GND), P1.B12 (GND)
/VBUS: J1.1, P1.A4 (VBUS), P1.A9 (VBUS), P1.B4 (VBUS), P1.B9 (VBUS)
/VCONN: J1.5, P1.B5 (VCONN)

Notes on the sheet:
VCONN
GND
VBUS

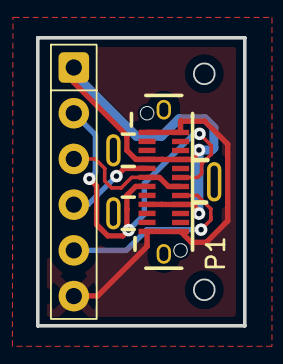
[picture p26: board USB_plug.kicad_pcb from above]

Board: 2 copper layers, 11.5 x 16.0 mm, 4 parts (0 on the bottom side), 6 nets.

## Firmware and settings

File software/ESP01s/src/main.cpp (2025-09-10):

#include <Arduino.h>
#include <ESP8266WiFi.h>
#include <ESP8266mDNS.h>   // mDNS / Bonjour
#include <Wire.h>
#include <LittleFS.h>
#include <WiFiManager.h>
#include <WiFiUdp.h>       

#include "Config.h"
#include "Measurement.h"
#include "SensorINA219.h"
#include "TimeService.h"
#include "DataLogger.h"
#include "WebServerMgr.h"

SensorINA219 sensor;
TimeService   timeSvc;
DataLogger    logger;
WebServerMgr  web(80);

Measurement latest;
unsigned long lastSample = 0;

// --- mDNS Helper ---
static bool mdnsRunning = false;

static void startMDNS() {
  MDNS.end(); // end any previous mDNS instance
  mdnsRunning = MDNS.begin("pd-logger");   // hostname "pd-logger.local"
  if (mdnsRunning) {
    MDNS.addService("http", "tcp", 80);
    Serial.println(F("mDNS ready: http://pd-logger.local"));
  } else {
    Serial.println(F("mDNS start failed"));
  }
}

void setup() {
  Serial.begin(115200);
  delay(200);
  Serial.println();
  Serial.println(F("Boot PD-Logger (Phase 2: Rotation)"));

  if (!LittleFS.begin()) {
    Serial.println(F("LittleFS start fehlgeschlagen!"));
  }

  // WiFi baseline
  WiFi.mode(WIFI_STA);
  WiFi.persistent(false);
  WiFi.setAutoReconnect(true);

  // Stability tweaks
  WiFi.setSleepMode(WIFI_NONE_SLEEP);       // reduce timing/handshake issues
  WiFi.setPhyMode(WIFI_PHY_MODE_11G);       // 11g often more robust than 11n
  WiFi.setOutputPower(17.0f);               // try 15–18 dBm if needed

  // Hostname for DHCP/Router & WiFiManager
  WiFi.hostname("PD-Logger");
  WiFiManager wm;
  wm.setHostname("PD-Logger");

  wm.setConnectTimeout(10);                 // 10 s connect attempt
  wm.setConfigPortalTimeout(120);           // 2 min captive portal
  wm.setBreakAfterConfig(true);             // return after successful connect

  const bool ok = wm.autoConnect("PD-Logger");
  Serial.printf("WiFi %s, IP=%s, RSSI=%d dBm\n",
                ok ? "connected" : "AP/Portal",
                WiFi.localIP().toString().c_str(),
                WiFi.RSSI());

  if (ok) {
    startMDNS();
    Serial.println(F("Reach me at: http://pd-logger.local"));
  }

  timeSvc.begin(TZ_EU_BERLIN);

  Wire.begin(PIN_SDA, PIN_SCL);
  if (!sensor.begin(Wire)) {
    Serial.println(F("INA219 nicht gefunden – Verkabelung/Adresse prüfen!"));
  }
  sensor.setShuntCorrection(INA219_CORR);
  Wire.setClock(100000);

  if (!logger.begin(LOG_DIR, LOG_PREFIX, LOG_EXT, MAX_LOG_FILE_SIZE, MAX_LOG_FILES)) {
    Serial.println(F("Logger init fehlgeschlagen!"));
  } else {
    Serial.print(F("Aktuelle Logdatei: "));
    Serial.println(logger.currentFilePath());
  }

  web.begin(&latest, &logger);

  lastSample = millis();
}

void loop() {
  web.loop();

  // mDNS needs regular updates
  MDNS.update();

  // Track WiFi state changes to (re)start mDNS on connect
  static wl_status_t lastStatus = WL_IDLE_STATUS;
  wl_status_t st = WiFi.status();
  if (st != lastStatus) {
    lastStatus = st;
    if (st == WL_CONNECTED) {
      if (!mdnsRunning) startMDNS();
      Serial.printf("Connected: IP=%s\n", WiFi.localIP().toString().c_str());
    } else {
      mdnsRunning = false;
      Serial.println(F("WiFi not connected"));
    }
  }

  // Keep NAT/ARP fresh with a tiny UDP packet to the gateway every 30s
  static unsigned long lastKA = 0;
  if (st == WL_CONNECTED && millis() - lastKA >= 30000UL) {
    lastKA = millis();
    IPAddress gw = WiFi.gatewayIP();
    if ((gw[0] | gw[1] | gw[2] | gw[3]) != 0) {  // valid gateway
      WiFiUDP udp;
      if (udp.begin(0)) {                        // ephemeral source port
        udp.beginPacket(gw, 9);                  // discard/chargen-like port
        uint8_t b = 0;
        udp.write(&b, 1);                        // 1 byte is enough
        udp.endPacket();
        udp.stop();
      }
    }
    yield(); // be nice to the WDT
  }

  // Sampling & Logging
  if (millis() - lastSample >= SAMPLE_INTERVAL_MS) {
    lastSample += SAMPLE_INTERVAL_MS;
    if (sensor.read(latest)) {
      latest.epoch = timeSvc.nowEpoch();
      latest.ms    = millis();
      // compact CSV logger uses "epoch;bus_mV;curr_mA"
      logger.append(latest, String());
    } else {
      Serial.println(F("Sensor read invalid -> skipped"));
    }
  }
}

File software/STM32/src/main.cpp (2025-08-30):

#include <Arduino.h>
#include <Wire.h>
#include <SSD1306Wire.h>
#include <Adafruit_INA219.h>

// ===================
// Konfiguration
// ===================

// Display: I2C an D2(SDA), D1(SCL), 64x48 Pixel
SSD1306Wire display(0x3C, D2, D1, GEOMETRY_64_48);

// INA219-Sensor
Adafruit_INA219 ina219;

// Anzeige- und Timing-Parameter
constexpr uint8_t  DISPLAY_WIDTH      = 64;
constexpr uint16_t UPDATE_INTERVAL_MS = 500;

// Shunt-Anpassung: 100 mΩ Standard → 50 mΩ real → Faktor 2
constexpr float SHUNT_CORRECTION = 2.0f;

unsigned long lastUpdate = 0;

// ===================
// Hilfsfunktionen
// ===================

/**
 * Berechnet die X-Position für zentrierten Text innerhalb der Displaybreite.
 */
static inline int centeredX(const String &text) {
  const int pixelWidth = display.getStringWidth(text);
  const int x = (DISPLAY_WIDTH - pixelWidth) / 2;
  return (x < 0) ? 0 : x;
}

/**
 * Zeichnet einen String zentriert auf gegebener Y-Position.
 */
static inline void drawCentered(int y, const String &text) {
  display.drawString(centeredX(text), y, text);
}

/**
 * Zeigt eine einzeilige Statusmeldung zentriert an.
 */
static inline void showStatus(const String &msg) {
  display.clear();
  display.setFont(ArialMT_Plain_16);
  drawCentered(12, msg);
  display.display();
}

// ===================
// Messwertanzeige
// ===================

void showMeasurements() {
  // Messwerte erfassen
  const float busVoltage_V    = ina219.getBusVoltage_V();    // VBUS
  const float shuntVoltage_mV = ina219.getShuntVoltage_mV(); // Shunt-Spannung (nur gelesen)
  float current_mA            = ina219.getCurrent_mA();
  float power_mW              = ina219.getPower_mW();

  // Shunt-Korrektur anwenden (50 mΩ statt 100 mΩ)
  current_mA *= SHUNT_CORRECTION;
  power_mW   *= SHUNT_CORRECTION;

  // Displayausgabe
  display.clear();
  display.setFont(ArialMT_Plain_16);

  String busVoltageStr = String(busVoltage_V, 2) + " V";
  drawCentered(0, busVoltageStr);

  String currentStr = String(current_mA, 0) + " mA";
  drawCentered(16, currentStr);

  String powerStr = String(power_mW / 1000.0f, 2) + " W";
  drawCentered(32, powerStr);

  display.display();

  // USB-Serial parallel ausgeben
  Serial.print("U = ");
  Serial.print(busVoltage_V, 2);
  Serial.print(" V   I = ");
  Serial.print(current_mA, 1);
  Serial.print(" mA   P = ");
  Serial.print(power_mW / 1000.0, 2);
  Serial.println(" W");

  (void)shuntVoltage_mV; // bewusst nicht verwendet
}

// ===================
// Arduino-Setup/Loop
// ===================

void setup() {
  Serial.begin(115200);

  // Auf verfügbare Serial warten (max. 1,5 s)
  const unsigned long t0 = millis();
  while (!Serial && (millis() - t0 < 1500)) { /* warten */ }
  Serial.println("Systemstart...");

  delay(1000);

  Wire.begin();

  // OLED initialisieren
  display.init();
  display.flipScreenVertically();  // richtige Ausrichtung
  display.clear();
  display.display();

  delay(500);

  // INA219 initialisieren und Status anzeigen
  if (!ina219.begin()) {
    showStatus("INA219 FAIL");
  } else {
    showStatus("INA219 OK");
  }
}

void loop() {
  const unsigned long now = millis();
  if (now - lastUpdate >= UPDATE_INTERVAL_MS) {
    lastUpdate = now;
    showMeasurements();
  }
}

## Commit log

2025-09-10 various improvements. Both pd_logger and power_meter fully functional
    [USB_PD_monitor.kicad_pcb, USB_PD_monitor.kicad_sch, USB_PD_monitor_V1.kicad_pcb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]
2025-09-10 3d print files added
    [PD_logger_case v15.3mf, USB_PD_monitor v23.3mf, USB_plug.step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]
